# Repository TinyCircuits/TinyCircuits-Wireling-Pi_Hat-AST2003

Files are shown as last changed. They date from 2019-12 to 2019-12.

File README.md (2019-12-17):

# TinyCircuits Wireling Pi Hat AST2003
# AST2003 Rev2

The design files are located under design_files/ for the TinyCircuits AST2003 Rev 2 PCB. This is a Pi Hat that allows Pi users to add up to 4 Wirelings to their project. 

Format is in Cadsoft Eagle format - Eagle version 6.2 was used for the original design.

For more infomation on this, check out the product page at TinyCircuits.com

# License:

Design by TinyCircuits.
All design files are released under the Creative Commons Attribution Share-Alike 3.0 License, see the following link for details: http://creativecommons.org/licenses/by-sa/3.0

All text above must be included in any redistribution or derived design

This project uses designs and concepts developed as part of the Arduino project and the LilyPad project.  The TinyCircuits design files themselves (schematics, PCB and libraries) are not directly derived from these works' design files and have been created new, however the concepts and basic architecture behind the TinyDuino and TinyLily products are derived and we thank the hard work of the organizations below for their contributions to open-source hardware:
  
Original Arduino Uno Design by Team Arduino

LilyPad Arduino Design by Leah Buechley and Sparkfun Electronics

Please support the open-source hardware community

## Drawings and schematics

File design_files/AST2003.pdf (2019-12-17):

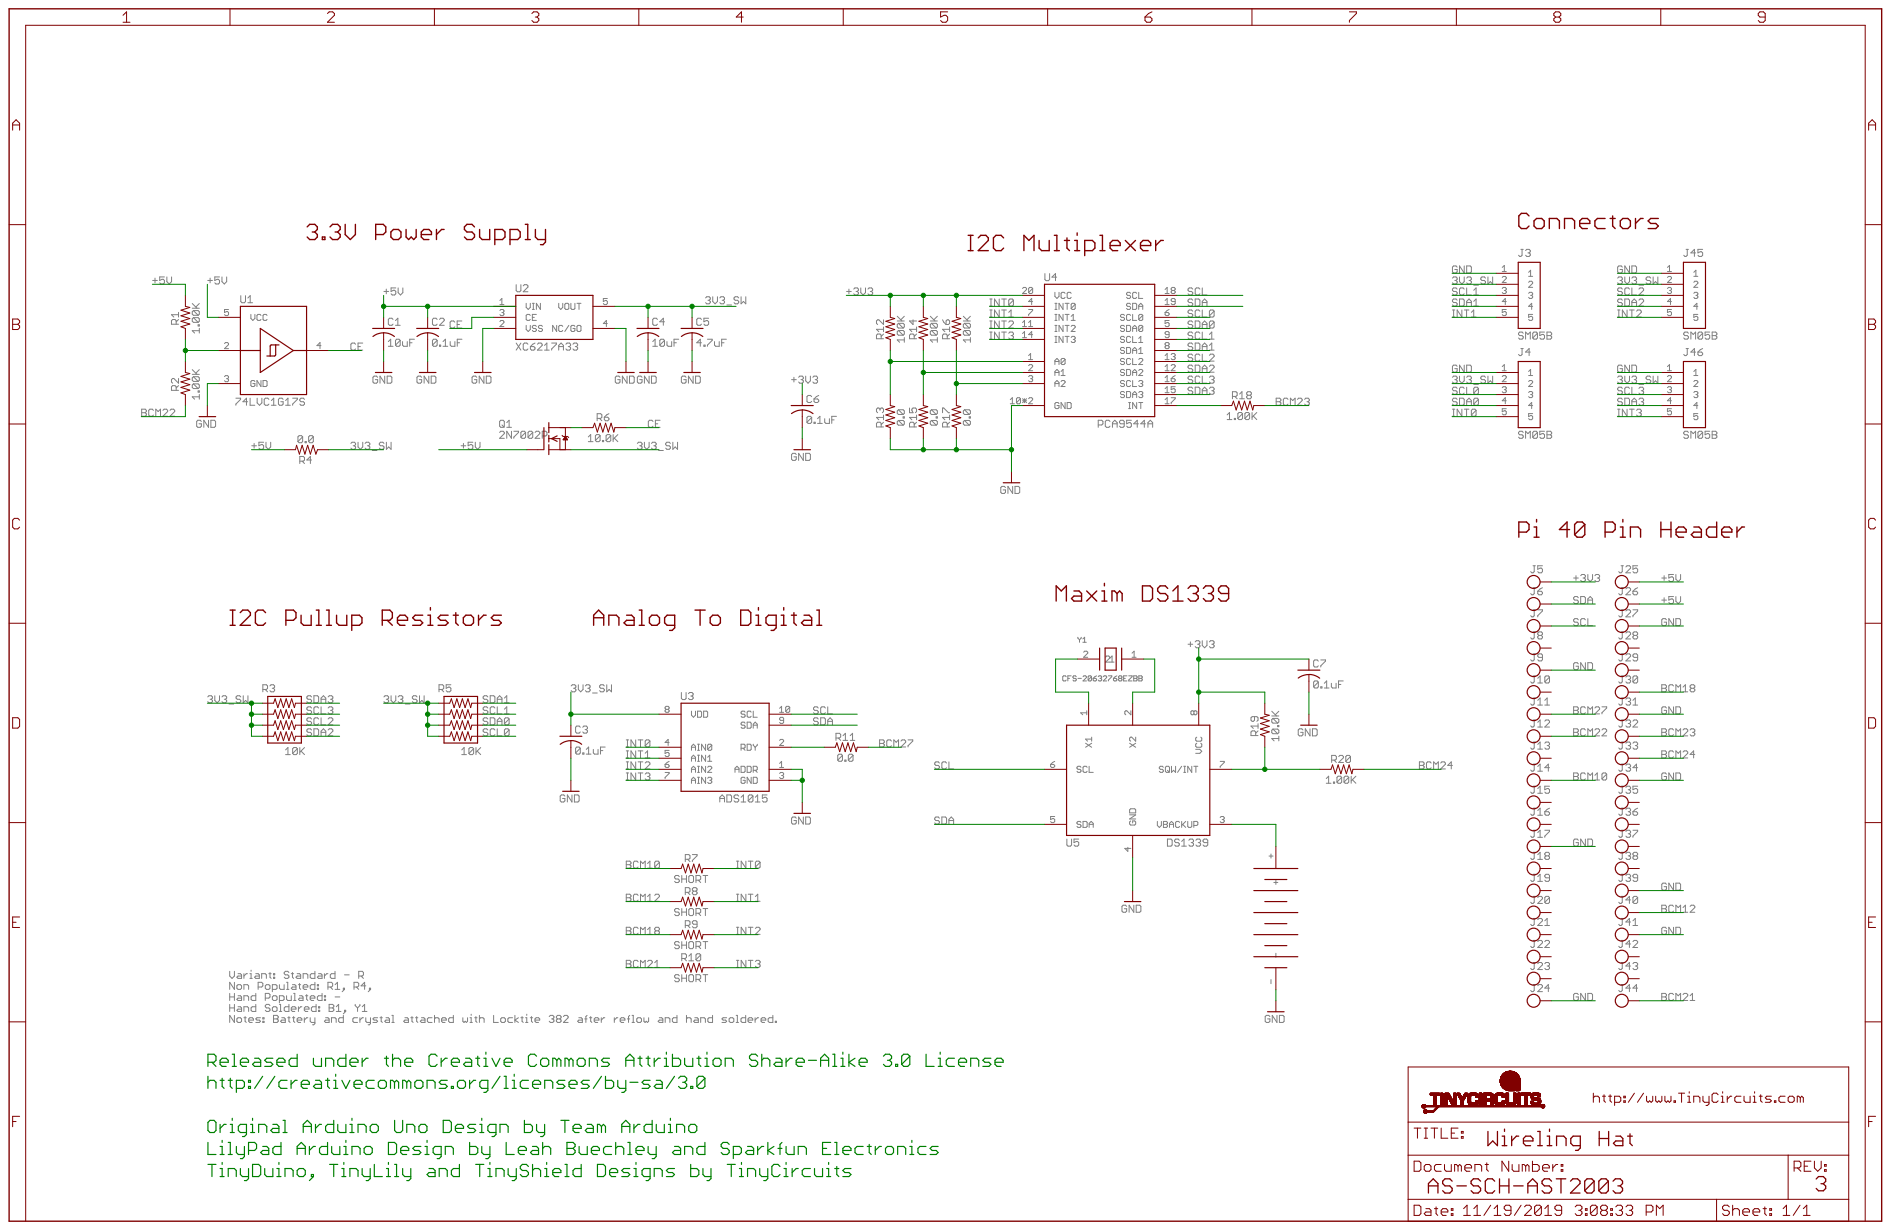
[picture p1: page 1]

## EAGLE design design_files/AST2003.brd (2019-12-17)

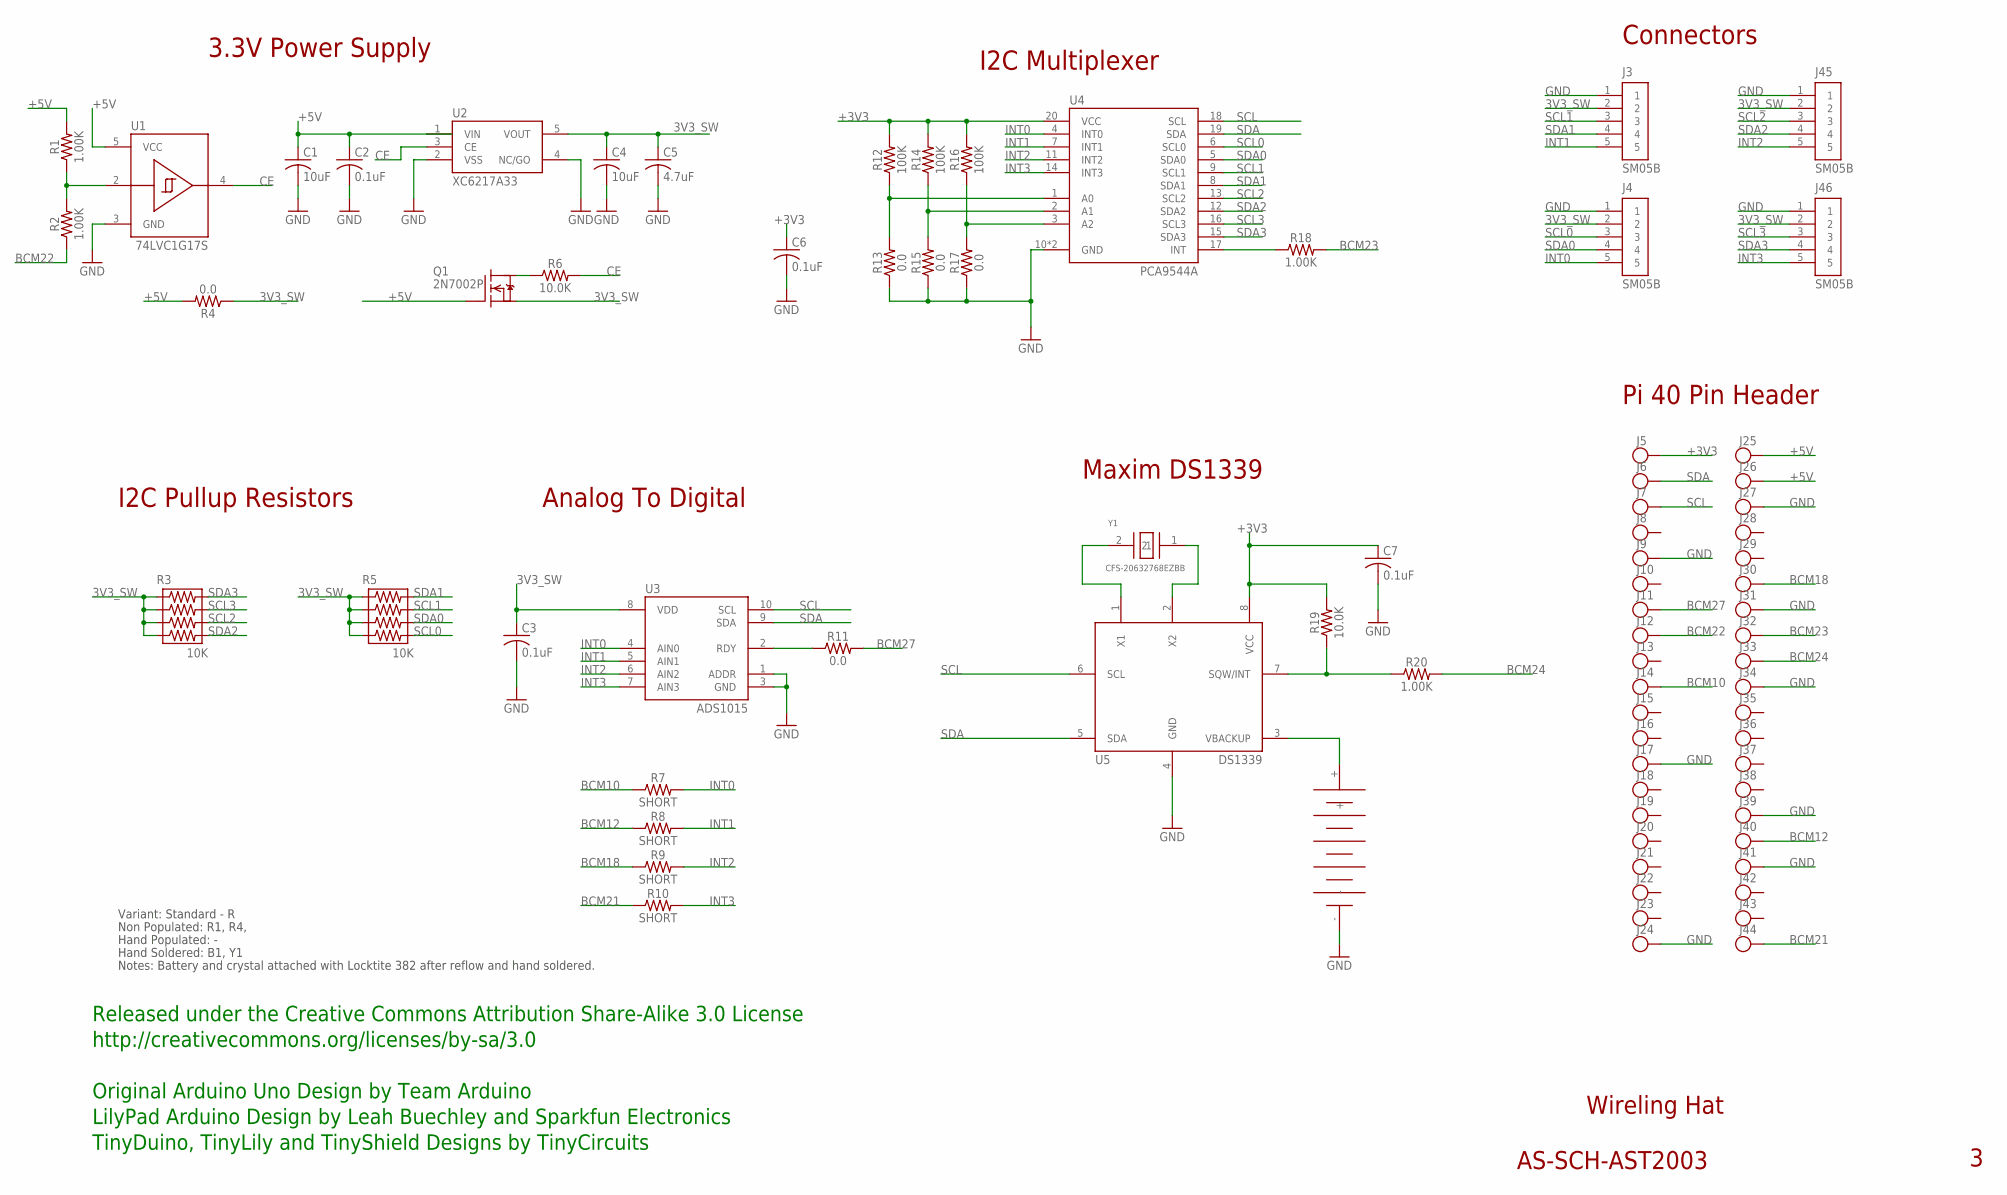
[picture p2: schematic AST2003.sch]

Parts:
B1: ML-920S/DN
C1, C4: 10uF; C0603; PARTNO AS-ITM-00002
C2, C6: 0.1uF; C0402; PARTNO AS-ITM-00008
C3, C7: 0.1uF; C0402
C5: 4.7uF; C0402; PARTNO AS-ITM-00242
J3, J4, J45, J46: SM05B; JST_SH_5X1
J5, J6, J7, J8, J9, J10, J11, J12, J13, J14, J15, J16, J17, J18, J19, J20, J21, J22, J23, J24, J25, J26, J27, J28, J29, J30, J31, J32, J33, J34, J35, J36, J37, J38, J39, J40, J41, J42, J43, J44: PIN_1X.1"1; 1X.1"_2
Q1: 2N7002P; SOT-416; PARTNO AS-ITM-00110
R1, R2, R20: 1.00K; 0402; PARTNO AS-ITM-00003
R3, R5: 10K; 0402RPACK; PARTNO AS-ITM-00520
R4, R13, R15, R17: 0.0; 0402; PARTNO AS-ITM-00076
R6, R19: 10.0K; 0402; PARTNO AS-ITM-00032
R7, R8, R9, R10: SHORT; 0402_SHORT
R11: 0.0; 0402
R12, R14, R16: 100K; 0402; PARTNO AS-ITM-00004
R18: 1.00K; 0402
U1: 74LVC1G17S; SOT-353
U2: XC6217A33; SOT-25; PARTNO AS-ITM-00249
U3: ADS1015; R-PQFP-N10
U4: PCA9544A; VQFN-20_4.5X3.5
U5: DS1339; 8-USOP
Y1: CFS-20632768EZBB; CRYSTAL_1.9MM_TH

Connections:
3V3_SW: C3.1, C4.1, C5.1, J3.2, J4.2, J45.2, J46.2, Q1.2 (S), R3.1, R3.3, R3.5, R3.7, R4.1, R5.1, R5.3, R5.5, R5.7, U2.5 (VOUT), U3.8 (VDD)
+3V3: C6.1, C7.1, J5.1, R12.2, R14.2, R16.2, R19.2, U4.20 (VCC), U5.8 (VCC)
+5V: C1.1, C2.1, J25.1, J26.1, Q1.1 (G), R1.2, R4.2, U1.5 (VCC), U2.1 (VIN)
BCM10: J14.1, R7.1
BCM12: J40.1, R8.1
BCM18: J30.1, R9.1
BCM21: J44.1, R10.1
BCM22: J12.1, R2.1
BCM23: J32.1, R18.2
BCM24: J33.1, R20.2
BCM27: J11.1, R11.2
CE: R6.2, U1.4 (Y), U2.3 (CE)
GND: B1.-, C1.2, C2.2, C3.2, C4.2, C5.2, C6.2, C7.2, J3.1, J4.1, J9.1, J17.1, J24.1, J27.1, J31.1, J34.1, J39.1, J41.1, J45.1, J46.1, R13.1, R15.1, R17.1, U1.3 (GND), U2.2 (VSS), U2.4 (NC/GO), U3.1 (ADDR), U3.3 (GND), U4.10 (GND), U4.PAD (GND), U5.4 (GND)
INT0: J4.5, R7.2, U3.4 (AIN0), U4.4 (INT0)
INT1: J3.5, R8.2, U3.5 (AIN1), U4.7 (INT1)
INT2: J45.5, R9.2, U3.6 (AIN2), U4.11 (INT2)
INT3: J46.5, R10.2, U3.7 (AIN3), U4.14 (INT3)
unnamed: Q1.3 (D), R6.1
unnamed: R12.1, R13.2, U4.1 (A0)
unnamed: R16.1, R17.2, U4.3 (A2)
unnamed: R18.1, U4.17 (INT)
unnamed: R14.1, R15.2, U4.2 (A1)
unnamed: R11.1, U3.2 (RDY)
unnamed: R19.1, R20.1, U5.7 (SQW/INT)
unnamed: B1.+, U5.3 (VBACKUP)
unnamed: U5.1 (X1), Y1.2 (1)
unnamed: U5.2 (X2), Y1.1 (2)
unnamed: R1.1, R2.2, U1.2 (A)
SCL: J7.1, U3.10 (SCL), U4.18 (SCL), U5.6 (SCL)
SCL0: J4.3, R5.8, U4.6 (SCL0)
SCL1: J3.3, R5.4, U4.9 (SCL1)
SCL2: J45.3, R3.6, U4.13 (SCL2)
SCL3: J46.3, R3.4, U4.16 (SCL3)
SDA: J6.1, U3.9 (SDA), U4.19 (SDA), U5.5 (SDA)
SDA0: J4.4, R5.6, U4.5 (SDA0)
SDA1: J3.4, R5.2, U4.8 (SDA1)
SDA2: J45.4, R3.8, U4.12 (SDA2)
SDA3: J46.4, R3.2, U4.15 (SDA3)

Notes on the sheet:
Wireling Hat
AS-SCH-AST2003
Released under the Creative Commons Attribution Share-Alike 3.0 License
http://creativecommons.org/licenses/by-sa/3.0
LilyPad Arduino Design by Leah Buechley and Sparkfun Electronics
TinyDuino, TinyLily and TinyShield Designs by TinyCircuits
Original Arduino Uno Design by Team Arduino
3.3V Power Supply
I2C Multiplexer
Connectors
Analog To Digital
I2C Pullup Resistors
Non Populated: R1, R4,
Hand Populated: -
Hand Soldered: B1, Y1
Notes: Battery and crystal attached with Locktite 382 after reflow and hand soldered.
Variant: Standard - R
Maxim DS1339
Pi 40 Pin Header

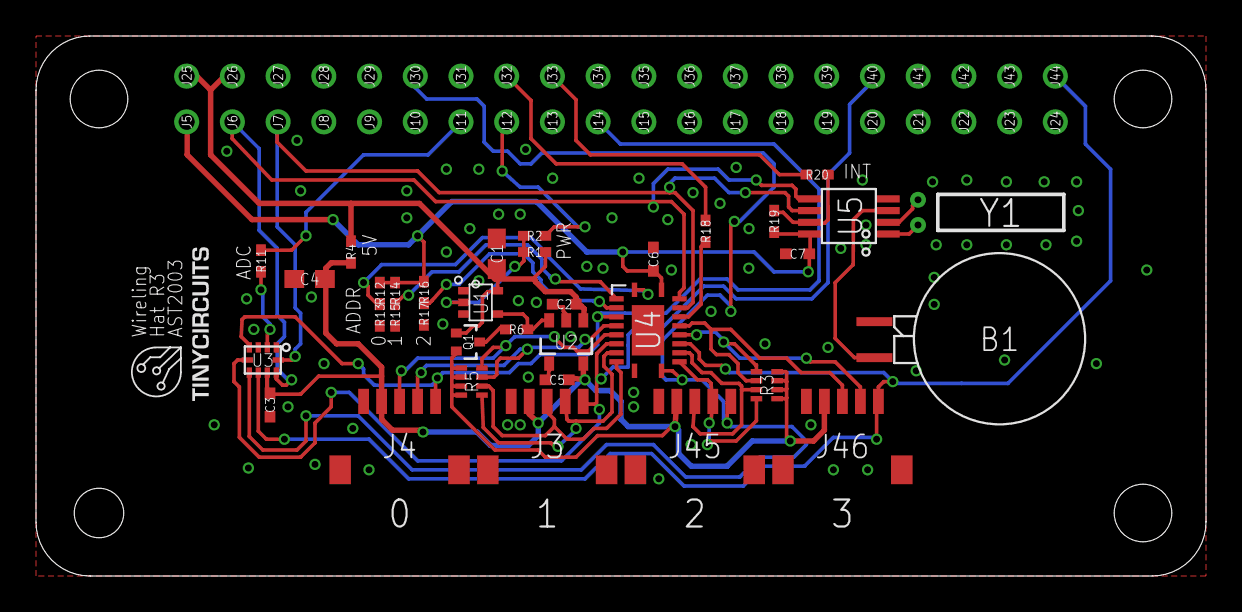
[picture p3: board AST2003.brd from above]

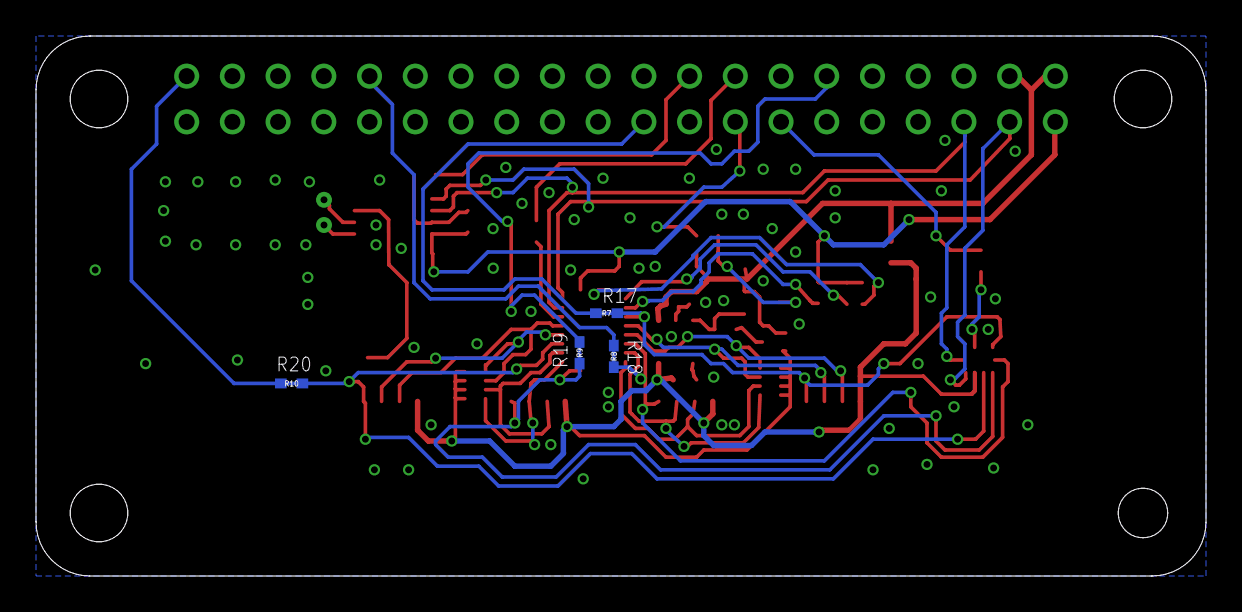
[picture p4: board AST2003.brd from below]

Board: 2 copper layers, 65.0 x 30.0 mm, 80 parts (4 on the bottom side), 38 nets.

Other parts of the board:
U$1: DOCFIELD-TINYCIRCUITS-PCB
